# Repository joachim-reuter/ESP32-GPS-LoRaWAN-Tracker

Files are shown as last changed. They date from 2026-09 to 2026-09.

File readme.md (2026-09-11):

# ESP32 GPS LoRaWAN Tracker
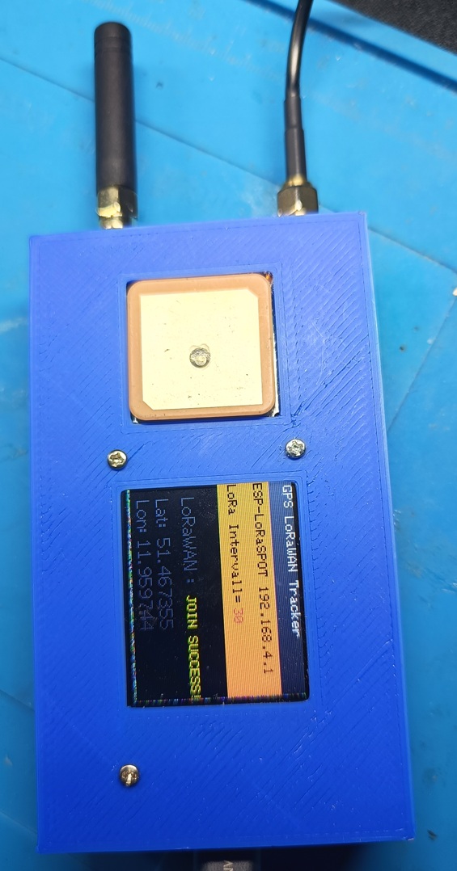
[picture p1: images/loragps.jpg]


GPS LoRaWAN-Tracker auf Basis eines ESP32 mit LoRa-Modul SX1262 und GPS-Modul NEO-7M, und TFT-Display

## Funktionen

Der Tracker zeichnet anhand der GPS- Daten die LoRa-WAN Verfügbarkeit auf. Über das TTN- Netzwerk werden die Koordinaten auf 

einem Raspi4 / OMV Datenspeicher abgelegt und können über einem WEB- Service ausgewertet werden.

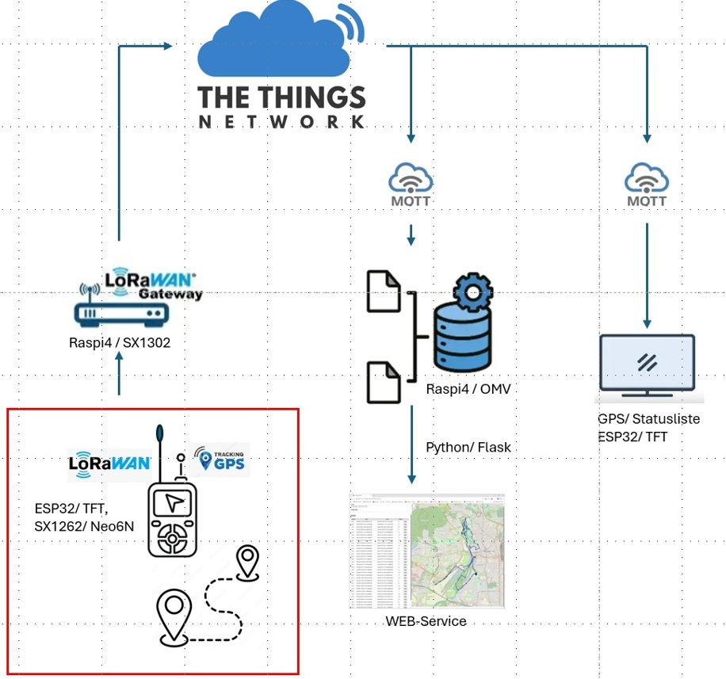
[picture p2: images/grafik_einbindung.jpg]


## Hardware

### Controller

* ESP32

### GPS

* NEO-7M Modul
* GPS / GLONASS / Galileo
* serielle Kommunikation

### LoRa

* SX 1262
* Kommunikation über Gateway Raspi4/SX1302 TTN
* Upload über TTN

### Display

* TFT
* 128 × 160 Pixel

user setup :

#define ST7735_DRIVER

#define ST7735_BLACKTAB   // <<< Wichtig für zentriertes Bild!

#define TFT_MOSI 23

#define TFT_SCLK 18

#define TFT_CS   5

#define TFT_DC   2

#define TFT_RST  4

#define TFT_MISO -1

#define LOAD_GLCD

#define LOAD_FONT2

#define LOAD_FONT4

#define SMOOTH_FONT

#define SPI_FREQUENCY 27000000

## Pinbelegung

### GPS

#define GPS_RX      16

#define GPS_TX      17

### LoRa

#define LORA_SCK   18

#define LORA_MISO  19

#define LORA_MOSI  23

#define LORA_CS    15

#define LORA_DIO1  33

#define LORA_RST   27

#define LORA_BUSY  32

## Schaltplan

#####################
Unter Ordner "Schaltplan" als PDF

## Software

# Vorbereitung Filesystem:

* _Little_FS_init.ino 

Sketch wird vor Laden der Software in den EEPROM geladen. Er dient zum Verwalten des Tracking- Intervalls 

## Code

* Projektdatei
  
GPS_LoRaWAN_Tracker.ino

* globale Konfiguration
  
config.h

* Displaymanagement
  
display.h

display.cpp

* Filesystem zum Verwalten des Tracking- Intervalls
  
filesystem.h

filesystem.cpp

* GPS- Funktionen
  
gps.h

gps.cpp

* LoRa- Funktionen
  
lorawan.h

lorawan.cpp

* lokaler Hotspot zur Einstellung des Intervalls über WEB- Seite
  
wifi_ap.h

wifi_ap.cpp

## Funktionen

Nach Einschalten kann sich über den lkokalen HotSpot: ESP-LoRaSPOT (192.168.4.1) auf eine WEB-Seite verbunden werden

und das Tracking- Intervall festgelegt werden, z.B. "30" für 30s

Der Tracker verbindet sich mit GPS. Wenn er GPS- Koordinaten gefunden hat und ein verfügbares LoRaWAN-Gateway sendet er die GPS- 

Daten und die Gateway- Informationen in das TTN. Über die Upload- Funktion werden die Daten auf einem OMV- Server abgelegt.

## Hinweise

Der GPS-Empfang ist abhängig von Umgebung, Antennenposition und Sicht zum Himmel.

Die Genauigkeit der aufgezeichneten Position und Höhe hängt von der Qualität der GNSS-Daten und den verwendeten Sensoren ab.

Der aktuelle Sketch verwendet einen festen WLAN-Access-Point mit den oben genannten Zugangsdaten.

## Autor

**Joachim Reuter**

## Version

**ESP32 GPS LoRaWAN Tracker – Version 2**

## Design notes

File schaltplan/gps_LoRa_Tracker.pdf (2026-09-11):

TFT_MISO | -1
TFT_MOSI | 23
TFT_SCLK | 18
TFT_CS | 5
TFT_DC | 2
TFT_RST | 4

# ESP32 WROOM

# TFT Display

LORA_SCK | 18
LORA_MISO | 19
LORA_MOSI | 23
LORA_CS | 15
LORA_DIO1 | 33
LORA_RST | 27
LORA_BUSY | 32

GPS_RX 16
GPS_TX 17

3,3 V

3,3 V

3,3 V

## LoRa SX1262

## GPS NEO-6M

GPS-Antenne indoor
(Test)

GPS-Antenne outdoor

LoRa-Antenne

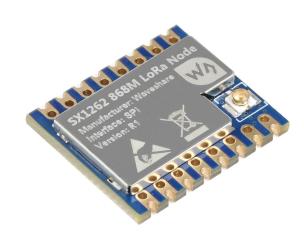
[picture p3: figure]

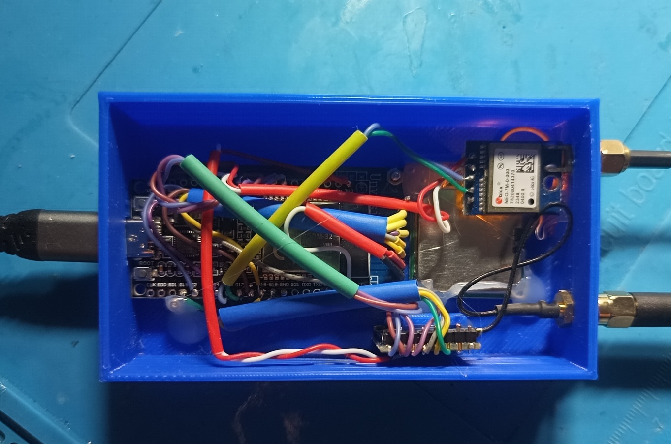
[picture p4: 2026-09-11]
images/loragps_innen.jpg

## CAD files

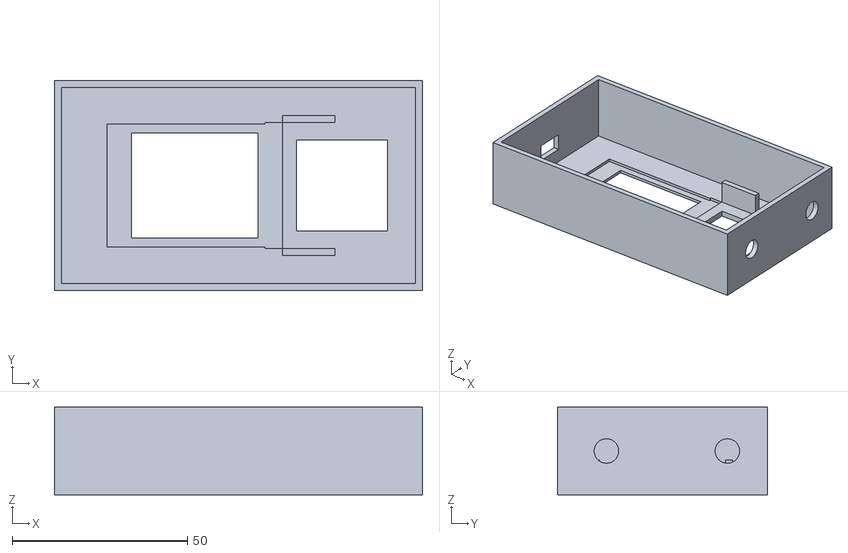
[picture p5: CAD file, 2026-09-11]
3d_druck/lora_gps_gehäuse_V1.stl
105.0 x 60.0 x 25.0

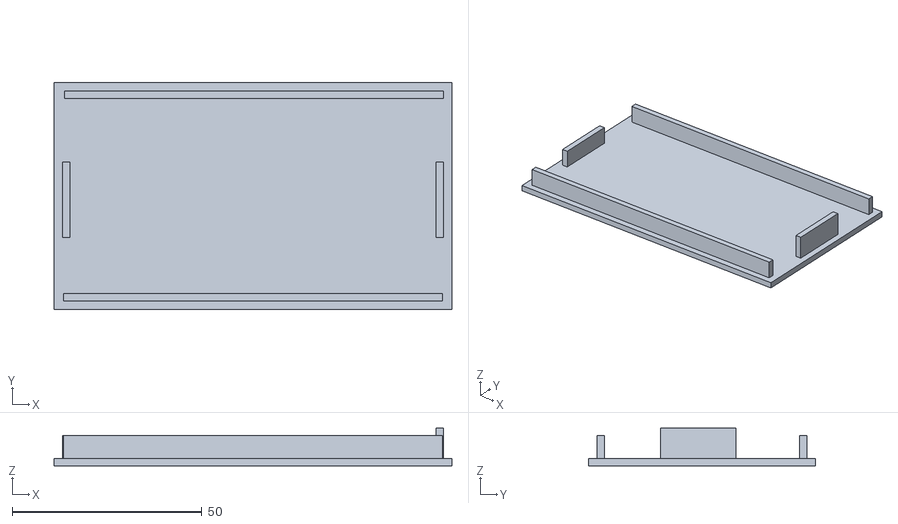
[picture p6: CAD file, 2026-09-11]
3d_druck/lora_gps_deckel_V1.stl
105.0 x 60.0 x 10.0

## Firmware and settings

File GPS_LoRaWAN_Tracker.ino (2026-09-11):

#include <WiFi.h>
#include <WebServer.h>
#include "config.h"
#include "display.h"
#include "filesystem.h"
#include "gps.h"
#include "wifi_ap.h"
#include "lorawan.h"


void setup()
{
    Serial.begin(115200); // For debug
    initDisplay();
    initFS();
    loadIntervall();
    initGPS();
    initWiFiAP();

    drawDisp();

    initLoRaWAN();
 

    
    
}

void loop()
{
    gpsLoop();
    wifiLoop();
    displayLoop();
    lorawanLoop();
    
    
}

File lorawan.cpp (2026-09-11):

#include <RadioLib.h>
#include <SPI.h>
#include "config.h"
#include "lorawan.h"
#include "gps.h"
#include "filesystem.h"

/*// ===================== PINOUT ESP32-WROOM =====================
#define LORA_SCK   18
#define LORA_MISO  19
#define LORA_MOSI  23

#define LORA_CS    15
#define LORA_DIO1  33
#define LORA_RST   27
#define LORA_BUSY  32
*/

// =================== Statusvariable für Anzeige ===============
String loVar = "";

// ===================== SPI =====================
SPIClass spil(VSPI);

// ===================== SX1262 =====================
SX1262 radio = new Module(LORA_CS, LORA_DIO1, LORA_RST, LORA_BUSY, spil);

// ===================== TTN KEYS =====================
// DevEUI
uint64_t devEUI  = 0x70B3D57ED0078496ULL;

// JoinEUI (bei dir all zeros)
uint64_t joinEUI = 0x0000000000000000ULL;

// Keys (LoRaWAN 1.0.3 -> identisch)
uint8_t nwkKey[16] = {
  0x34,0xB8,0x16,0xB2,0xEF,0x76,0xFE,0x72,
  0x9F,0x44,0xEA,0xE4,0x37,0x7B,0x6D,0x31
};

uint8_t appKey[16] = {
  0x34,0xB8,0x16,0xB2,0xEF,0x76,0xFE,0x72,
  0x9F,0x44,0xEA,0xE4,0x37,0x7B,0x6D,0x31
};

// ===================== REGION =====================
const LoRaWANBand_t region = EU868;
const uint8_t subBand = 0;

// ===================== NODE =====================
LoRaWANNode node(&radio, &region, subBand);

void initLoRaWAN()
{
  Serial.println("\n===============================");
  Serial.println("TTN SX1262 OTAA TEST START");
  Serial.println("===============================");

  loVar = "LoRa Start...";

  // SPI start
  spil.begin(LORA_SCK, LORA_MISO, LORA_MOSI, LORA_CS);

  // Radio init
  Serial.println("Init radio...");
  ConfigLoRa_t config;
  config.frequency = 868;

  int state = radio.begin(config);

  Serial.print("radio.begin = ");
  Serial.println(state);

  if(state != RADIOLIB_ERR_NONE) {
    Serial.println("❌ Radio init failed!");
    while(true);
  }

  // OTAA join
  Serial.println("Joining TTN...");

  state = node.beginOTAA(joinEUI, devEUI, nwkKey, appKey);

  if(state != RADIOLIB_ERR_NONE) {
    Serial.print("OTAA init failed: ");
    Serial.println(state);
    while(true);
  }

  state = node.activateOTAA();

  if(state != RADIOLIB_LORAWAN_NEW_SESSION) {
    Serial.print("Join failed: ");
    Serial.println(state);
    while(true);
  }
  loVar = "JOIN SUCCESS!";
  Serial.println("✅ JOIN SUCCESS!");
}


void lorawanLoop()
{

  // Senderintervall einstellen
  static uint32_t lastSend = 0;

  // Intervall aus LittleFS/Webinterface
  uint32_t interval = intervar.toInt() * 1000UL;

  // Sicherheit
  if (interval == 0)
      interval = 60000;

  // Noch nicht Zeit zum Senden
  if (millis() - lastSend < interval)
      return;

  lastSend = millis();



  // Nur senden, wenn GPS gültig ist
  if (!gpsValid())
  {
      Serial.println("Kein GPS Fix - kein Uplink");
      delay(1000);
      return;
  }

  Serial.println("Sending uplink...");

  // GPS auf 5 Nachkommastellen skalieren
  int32_t lat = (int32_t)(latVar * 100000.0);
  int32_t lon = (int32_t)(lonVar * 100000.0);

  // 9 Byte:
  // 0-3 = Latitude
  // 4-7 = Longitude
  // 8   = Logging
  uint8_t payload[9];

  payload[0] = (lat >> 24) & 0xFF;
  payload[1] = (lat >> 16) & 0xFF;
  payload[2] = (lat >> 8)  & 0xFF;
  payload[3] = lat & 0xFF;

  payload[4] = (lon >> 24) & 0xFF;
  payload[5] = (lon >> 16) & 0xFF;
  payload[6] = (lon >> 8)  & 0xFF;
  payload[7] = lon & 0xFF;

  // Logging
  payload[8] = 1;

  Serial.print("LAT: ");
  Serial.println(latVar, 8);

  Serial.print("LON: ");
  Serial.println(lonVar, 8);

  Serial.print("Payload HEX: "); 

  for (int i = 0; i < 9; i++)
  {
      if (payload[i] < 0x10)
          Serial.print("0");

      Serial.print(payload[i], HEX);
      Serial.print(" ");
  }

  Serial.println();

  int state = node.sendReceive(payload, sizeof(payload));



  Serial.print("sendReceive returned = ");
  Serial.println(state);


  if(state == RADIOLIB_ERR_NONE) {
    Serial.println("✔ Uplink OK");
  } 
  else
  {
    Serial.print("❌ Uplink Fehler: ");
    Serial.println(state);
  }

 


}

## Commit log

2026-09-11 Update user setup and pin configuration in README
2026-09-11 Add image link for ESP32 GPS LoRaWAN Tracker
2026-09-11 Add image to README for ESP32 GPS LoRaWAN Tracker
    Added an image of the ESP32 GPS LoRaWAN Tracker to the README.
